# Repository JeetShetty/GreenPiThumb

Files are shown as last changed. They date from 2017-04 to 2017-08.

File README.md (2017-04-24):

# GreenPiThumb




GreenPiThumb is a program that automatically waters a plant based on soil moisture levels, and records and displays the following:

* Ambient temperature
* Ambient humidity
* Ambient light
* Soil moisture level
* Photographs of the plant

## Installation

### Standard Installation

Run this on a Raspberry Pi device:

```bash
sudo apt-get update
sudo apt-get install build-essential python-dev python-picamera
git clone https://github.com/adafruit/Adafruit_Python_DHT.git
cd Adafruit_Python_DHT
python setup.py install

cd ..
git clone https://github.com/JeetShetty/GreenPiThumb.git
cd GreenPiThumb
sudo pip install -r requirements.txt
cp greenpithumb/wiring_config.ini.example greenpithumb/wiring_config.ini
```

#### Running GreenPiThumb

After running the above installation steps on your Pi, run GreenPiThumb with a command following the template below:

```bash
sudo python greenpithumb/greenpithumb.py \
  --poll_interval 15 \
  --photo_interval 240 \
  --sleep_window "23:15-07:00" \
  --sleep_window "14:30-15:45" \
  --image_path "images/" \
  --moisture_threshold 900
```

### Dev Installation

Run this on a system for development:

```bash
sudo apt-get update
sudo apt-get install build-essential python-dev
git clone https://github.com/adafruit/Adafruit_Python_DHT.git
cd Adafruit_Python_DHT
sudo python setup.py install --force-test

cd ..
git clone https://github.com/JeetShetty/GreenPiThumb.git
cd GreenPiThumb
sudo pip install -r requirements.txt
sudo pip install -r dev_requirements.txt
cp greenpithumb/wiring_config.ini.example greenpithumb/wiring_config.ini
```

### Ansible Installation

This repository contains the GreenPiThumb backend, but GreenPiThumb also offers a [web frontend](https://github.com/JeetShetty/GreenPiThumb_Frontend_static) so you can check status of GreenPiThumb in your browser.

The instructions below explain how to install all backend and frontend components of GreenPiThumb to a Raspberry Pi device.

#### Local Self-Provision

If you're not familiar with Ansible, the simplest way to deploy GreenPiThumb is to install Ansible on the Pi itself and then use Ansible to self-provision the machine.

From a shell on the Raspberry Pi device itself, enter the following:

```bash
sudo apt-get update

# Install Ansible and dependencies
sudo apt-get install -y \
  libffi-dev \
  libyaml-dev \
  libpython2.7-dev \
  libssl-dev \
  python-pip \
  python2.7-dev
sudo pip install ansible paramiko PyYAML Jinja2 httplib2 six

# Install the Ansible GreenPiThumb role
sudo ansible-galaxy install JeetShetty.ansible-role-greenpithumb

# Create a minimal Ansible playbook to install GreenPiThumb
echo "- hosts: localhost
  roles:
    - { role: JeetShetty.ansible-role-greenpithumb }" > install.yml

# Self-provision for GreenPiThumb
sudo ansible-playbook install.yml
```

After this process completes, GreenPiThumb's backend and frontend will be running as services on the Pi. If you navigate to the Pi in a web browser (e.g. http://raspberrypi/ for a Pi named `raspberrypi`), you will see a dashboard similar to [greenpithumb.mtlynch.io](http://greenpithumb.mtlynch.io).

#### Remote Deployment

You can also use Ansible to deploy GreenPiThumb to a Raspberry Pi device from another Linux machine on the same network. You'll need to [install Ansible](http://docs.ansible.com/ansible/intro_installation.html) on your deployment machine (the non-Pi system).

Run the following commands on a Linux machine that has network access to your Pi device (e.g. on same local network):

```bash
PI_USER=pi                 # Change to the user on your Pi
PI_HOSTNAME=raspberrypi    # Change to your Pi's hostname.

# Install the Ansible GreenPiThumb role
sudo ansible-galaxy install JeetShetty.ansible-role-greenpithumb

# Create a minimal Ansible playbook to install GreenPiThumb
echo "- hosts: all
  roles:
    - { role: JeetShetty.ansible-role-greenpithumb}" > install.yml

# Provision the Pi using the playbook.
ansible-playbook install.yml \
  --user "${PI_USER}" \
  --ask-pass \
  --ask-sudo-pass \
  --become \
  --become-method sudo \
  -i "${PI_HOSTNAME},"
```

Ansible will prompt you for a password. Enter the password for the `PI_USER` account.

After this process completes, GreenPiThumb's backend and frontend will be running as services on the Pi. If you navigate to the Pi in a web browser (e.g. http://raspberrypi/ for a Pi named `raspberrypi`), you will see a dashboard similar to [greenpithumb.mtlynch.io](http://greenpithumb.mtlynch.io).

## Hardware

GreenPiThumb is designed for compatibility with a [Raspberry Pi device](https://www.raspberrypi.org/products/) running the [Raspbian OS](https://www.raspberrypi.org/downloads/raspbian/).

An example wiring can be found below:

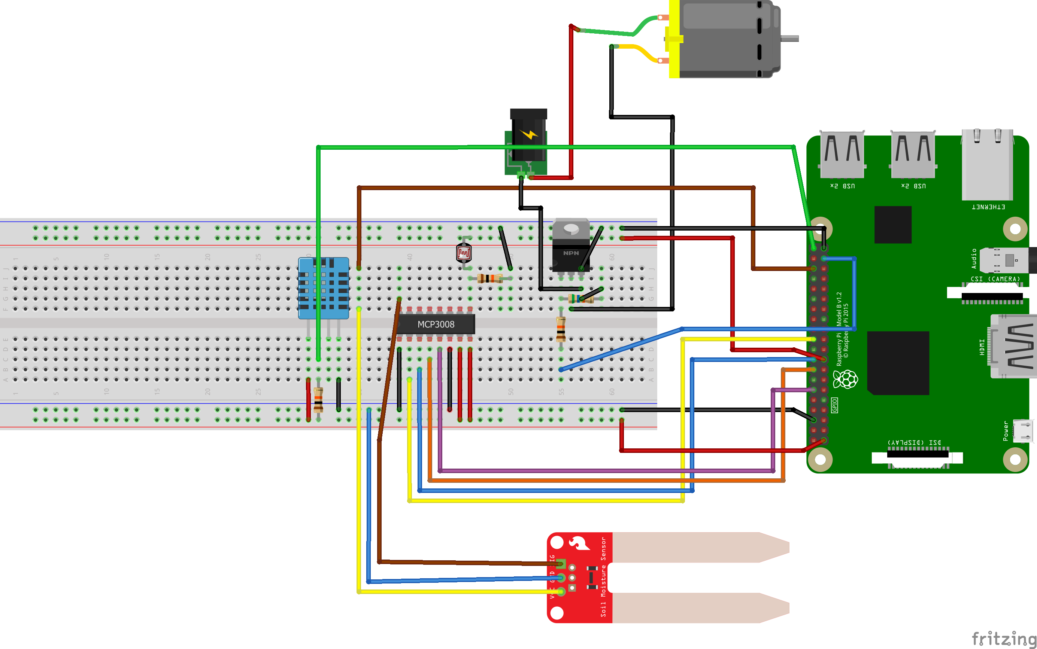
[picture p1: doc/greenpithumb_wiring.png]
Fritzing wiring diagram


The Fritzing diagram file for this diagram is available in the [`doc` folder](doc/).

## Related Repositories

* [GreenPiThumb_Frontend](https://github.com/JeetShetty/GreenPiThumb_Frontend): Web API to provide status about GreenPiThumb.
* [GreenPiThumb_Frontend_static](https://github.com/JeetShetty/GreenPiThumb_Frontend_static): An AngularJS web app for viewing GreenPiThumb status (the static portion of the web frontend).
* [ansible-role-greenpithumb](https://github.com/JeetShetty/ansible-role-greenpithumb): An [Ansible](https://www.ansible.com/how-ansible-works) role for deploying all parts of GreenPiThumb to a system.

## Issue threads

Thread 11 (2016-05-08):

DHT11 error code checking in humidity_sensor.py and temperature_sensor.py

JeetShetty, 2016-05-08:
Need to replace manually entered constants with constants from dht11 module

Closed 2016-06-28.

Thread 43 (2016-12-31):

Integrate GPIO stuff in moisture sensor

mtlynch, 2016-12-31:
I realized the code for `moisture_sensor.py` omits some critical elements we need. The moisture sensor is powered by the GPIO pins, because I think if we leave it powered all the time, the copper starts to corrode.

We can see how Dickson Chow does it here:

https://github.com/dicksondickson/PlantFriends/blob/7c172e9f80c2de2fdfc373d31a89de66787a7756/sensor_node/RFM69/sensor_node.ino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

So it looks like what we need to do is:

1. Set one pin to high, one pin to low
1. Read the sensor value from the ADC
1. Set both pins to low
1. Wait for capacitive effects to go away (he waits 88 milliseconds)
1. Repeat 1-2, but with the pins swapped and inverting the value from 1023
1. Turn off both pins
1. Average the two readings as the moisture level

JeetShetty, 2017-01-03:
What pins are we writing to in step 1? I'm confused about how this works through the ADC.

mtlynch, 2017-01-04:
So there 6 GPIO pins in play here. The ADC needs 4 pins, but the `moisture_sensor` module doesn't care about those 4 pins because it just needs an ADC instance (the instance worries about those pins and abstracts it away from `moisture_sensor`).

BUT `moisture_sensor` needs to control power to the sensor, so it needs to use two GPIO pins as output so that it can turn power on and off to the moisture sensor. Then it needs to know which ADC channel the moisture sensor is plugged into. In our schematic, the moisture sensor is plugged into ADC channel 7.

This is the quick 'n dirty script I used to test the soil moisture sensor as a standalone program. The numbers match the Fritzing schematic we have for the wiring.

```python
import time

import Adafruit_MCP3008
import RPi.GPIO as GPIO

# mtlynch: The moisture_sensor module wouldn't need to care about this stuff because it'd
# have an ADC initialized already
CLK  = 18
MISO = 23
MOSI = 24
CS   = 25
mcp = Adafruit_MCP3008.MCP3008(clk=CLK, cs=CS, miso=MISO, mosi=MOSI)

# Below this line is going to be kind of similar to what we want to do in moisture_sensor
ADC_CHANNEL_MOISTURE_SENSOR = 7

GPIO_PIN_1 = 16
GPIO_PIN_2 = 12

GPIO.setmode(GPIO.BCM)
GPIO.setup(GPIO_PIN_1, GPIO.OUT)
GPIO.setup(GPIO_PIN_2, GPIO.OUT)

i = 0
print('Reading MCP3008 values, press Ctrl-C to quit...')
# mtlynch: This just reads in a loop and alternates which pin has power on each iteration.
# In moisture_sensor, we'd want to read once with (pin_1 high, pin_2 low) and once with
# (pin_1 low, pin_2 high) and take the average.
while True:
    if i % 2 == 0:
        GPIO.output(GPIO_PIN_1, GPIO.LOW)
        GPIO.output(GPIO_PIN_2, GPIO.HIGH)
    else:
        GPIO.output(GPIO_PIN_1, GPIO.HIGH)
        GPIO.output(GPIO_PIN_2, GPIO.LOW)
    reading = mcp.read_adc(ADC_CHANNEL_MOISTURE_SENSOR)
    if i % 2 == 1:
        reading = 1023 - reading
    print reading
    time.sleep(0.5)
    i += 1
```

Closed 2017-01-20.

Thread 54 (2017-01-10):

Add GPIO.setmode

JeetShetty, 2017-01-10:
Seems to me that we want to use GPIO.BOARD, but you used GPIO.BCM in some of your code. I'm not clear on what each does, though.

mtlynch, 2017-01-12:
`GPIO.BCM` matches the numbers printed on the [Raspberry Pi cobbler](http://a.co/234GrbU) we use and in Fritzing.

I think the upside of `GPIO.BOARD` is that it will work across Raspberry Pi versions, but I'd rather sacrifice that to eliminate the confusion of having to keep looking at [this diagram](http://www.raspberrypi-spy.co.uk/wp-content/uploads/2012/06/Raspberry-Pi-GPIO-Layout-Model-B-Plus-rotated-2700x900-1024x341.png) to map the board numbers to the board-independent numbers.

Closed 2017-01-21.

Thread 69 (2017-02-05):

Connect pollers to actual database

mtlynch, 2017-02-05:
We have pollers that know how to write data to the database, but they're not hooked up to anything yet, so we need to add logic to the main script (greenpithumb.py) to connect each sensor to its appropriate poller and the pollers to the real sqlite database.

mtlynch, 2017-03-23:
Fixed in #89

Closed 2017-03-23.

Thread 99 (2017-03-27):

Can't kill GreenPiThumb with Ctrl+C

mtlynch, 2017-03-27:
Because of something weird we're doing with threading, GreenPiThumb doesn't exit when the user performs a `KeyboardInterrupt` (hits Ctrl+C). It eventually quits on the next poll, but the user can't quit immediately.

I think it's because the main thread is stuck blocking on reading from the record processing queue and can't be interrupted until something comes through.

Closed 2017-03-31.

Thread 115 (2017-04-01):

Camera Manager should name files based on UTC time zone

mtlynch, 2017-04-01:
We're going to run into issues parsing the files back otherwise (like #101) and it'll be good for all of our persistent storage to be in UTC time zone.

mtlynch, 2017-04-01:
Also we can probably drop the millisecond level precision here too.

Closed 2017-04-05.

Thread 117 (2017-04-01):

Camera poller needs to close camera manager

mtlynch, 2017-04-01:
Camera Manager needs to be closed when it is no longer needed, but the poller is not closing it.

Closed 2017-04-08.

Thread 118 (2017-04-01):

Camera manager should not take pictures at night

mtlynch, 2017-04-01:
We should integrate with the light sensor to detect when it's too dark to take a photo

JeetShetty, 2017-04-14:
Can I just add the light sensor to the ```_CameraPollWorker``` class? Are there any issues with the light sensor being read too frequently?

mtlynch, 2017-04-15:
Yeah that should work. I don't think there's much of a cost to reading the light sensor a lot.

Closed 2017-04-19.

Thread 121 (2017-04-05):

Drop seconds-level granularity

mtlynch, 2017-04-05:
Seconds-level granularity doesn't really make sense for anything in GreenPiThumb. The user doesn't need to schedule sensor polling intervals at the level of seconds and it doesn't make sense to take a picture of a plant at a frequency > 1x per min.

We should:
* Change command-line flags to take minutes rather than seconds
* Change the database to drop the seconds from the serialized timestamps

Closed 2017-04-07.

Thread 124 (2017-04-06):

Need to lower pump_manager's threshold for pumping

mtlynch, 2017-04-06:
The moisture I'm getting for dry soil is 860. We expected it to not water until it got below 300, so we need to increase the threshold a bit.

mtlynch, 2017-04-07:
Fixed in #126.

Closed 2017-04-07.

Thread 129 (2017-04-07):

Moisture threshold assumes constant temperature

mtlynch, 2017-04-07:
The temperature of the soil affects how conductive it is, but the soil moisture threshold does not take into account temperature (assumes soil's conductivity is fixed regardless of temperature).

We may want to use a more sophisticated threshold that takes temperature into consideration if temperature changes effect GreenPiThumb's soil moisture readings significantly.

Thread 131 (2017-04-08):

Pre-commit hook doesn't block on YAPF diff

mtlynch, 2017-04-08:
The pre-commit hook should block the commit if the YAPF diff turns up a delta, but currently it seems to just print a message and keep going. We should change the `build` so that it returns a failing exit code on a non-zero diff.

mtlynch, 2017-04-09:
Apparently this is a behavior change in YAPF:

https://github.com/google/yapf/issues/325

They're considering a fix, but there's a workaround possible:

https://github.com/google/yapf/issues/325#issuecomment-261552890

Closed 2017-04-13.

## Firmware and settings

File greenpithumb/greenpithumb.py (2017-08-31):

import argparse
import contextlib
import datetime
import logging
import Queue
import time

import Adafruit_DHT
import Adafruit_MCP3008
import picamera
import RPi.GPIO as GPIO

import adc_thread_safe
import camera_manager
import clock
import db_store
import dht11
import humidity_sensor
import light_sensor
import pi_io
import poller
import pump
import pump_history
import record_processor
import sleep_windows
import soil_moisture_sensor
import temperature_sensor
import wiring_config_parser

logger = logging.getLogger(__name__)


def configure_logging(verbose):
    """Configure the root logger for log output."""
    root_logger = logging.getLogger()
    handler = logging.StreamHandler()
    formatter = logging.Formatter(
        '%(asctime)s %(name)-15s %(levelname)-4s %(message)s',
        '%Y-%m-%d %H:%M:%S')
    handler.setFormatter(formatter)
    root_logger.addHandler(handler)
    if verbose:
        root_logger.setLevel(logging.INFO)
    else:
        root_logger.setLevel(logging.WARNING)


def read_wiring_config(config_filename):
    """Parses wiring config from a file."""
    logger.info('reading wiring config at "%s"', config_filename)
    with open(config_filename) as config_file:
        return wiring_config_parser.parse(config_file.read())


def make_adc(wiring_config):
    """Creates ADC instance based on the given wiring_config.

    Args:
        wiring_config: Wiring configuration for the GreenPiThumb.

    Returns:
        An ADC instance for the specified wiring config.
    """
    # The MCP3008 spec and Adafruit library use different naming for the
    # Raspberry Pi GPIO pins, so we translate as follows:
    # * CLK -> CLK
    # * CS/SHDN -> CS
    # * DOUT -> MISO
    # * DIN -> MOSI
    return adc_thread_safe.Adc(
        Adafruit_MCP3008.MCP3008(
            clk=wiring_config.gpio_pins.mcp3008_clk,
            cs=wiring_config.gpio_pins.mcp3008_cs_shdn,
            miso=wiring_config.gpio_pins.mcp3008_dout,
            mosi=wiring_config.gpio_pins.mcp3008_din))


def make_dht11_sensors(wiring_config):
    """Creates sensors derived from the DHT11 sensor.

    Args:
        wiring_config: Wiring configuration for the GreenPiThumb.

    Returns:
        A two-tuple where the first element is a temperature sensor and the
        second element is a humidity sensor.
    """
    local_dht11 = dht11.CachingDHT11(
        lambda: Adafruit_DHT.read_retry(Adafruit_DHT.DHT11, wiring_config.gpio_pins.dht11),
        clock.Clock())
    return temperature_sensor.TemperatureSensor(
        local_dht11), humidity_sensor.HumiditySensor(local_dht11),


def make_soil_moisture_sensor(adc, raspberry_pi_io, wiring_config):
    return soil_moisture_sensor.SoilMoistureSensor(
        adc, raspberry_pi_io, wiring_config.adc_channels.soil_moisture_sensor,
        wiring_config.gpio_pins.soil_moisture)


def make_light_sensor(adc, wiring_config):
    return light_sensor.LightSensor(adc,
                                    wiring_config.adc_channels.light_sensor)


def make_camera_manager(rotation, image_path, light_sensor):
    """Creates a camera manager instance.

    Args:
        rotation: The amount (in whole degrees) to rotate the camera image.
        image_path: The directory in which to save images.
        light_sensor: A light sensor instance.

    Returns:
        A CameraManager instance with the given settings.
    """
    camera = picamera.PiCamera(resolution=picamera.PiCamera.MAX_RESOLUTION)
    camera.rotation = rotation
    return camera_manager.CameraManager(image_path,
                                        clock.Clock(), camera, light_sensor)


def make_pump_manager(moisture_threshold, sleep_windows, raspberry_pi_io,
                      wiring_config, pump_amount, db_connection, pump_interval):
    """Creates a pump manager instance.

    Args:
        moisture_threshold: The minimum moisture level below which the pump
            turns on.
        sleep_windows: Sleep windows during which pump will not turn on.
        raspberry_pi_io: pi_io instance for the GreenPiThumb.
        wiring_config: Wiring configuration for the GreenPiThumb.
        pump_amount: Amount (in mL) to pump on each run of the pump.
        db_connection: Database connection to use to retrieve pump history.
        pump_interval: Maximum amount of time between pump runs.

    Returns:
        A PumpManager instance with the given settings.
    """
    water_pump = pump.Pump(raspberry_pi_io,
                           clock.Clock(), wiring_config.gpio_pins.pump)
    pump_scheduler = pump.PumpScheduler(clock.LocalClock(), sleep_windows)
    pump_timer = clock.Timer(clock.Clock(), pump_interval)
    last_pump_time = pump_history.last_pump_time(
        db_store.WateringEventStore(db_connection))
    if last_pump_time:
        logger.info('last watering was at %s', last_pump_time)
        time_remaining = max(
            datetime.timedelta(seconds=0),
            (last_pump_time + pump_interval) - clock.Clock().now())
    else:
        logger.info('no previous watering found')
        time_remaining = datetime.timedelta(seconds=0)
    logger.info('time until until next watering: %s', time_remaining)
    pump_timer.set_remaining(time_remaining)
    return pump.PumpManager(water_pump, pump_scheduler, moisture_threshold,
                            pump_amount, pump_timer)


def make_sensor_pollers(poll_interval, photo_interval, record_queue,
                        temperature_sensor, humidity_sensor,
                        soil_moisture_sensor, light_sensor, camera_manager,
                        pump_manager):
    """Creates a poller for each GreenPiThumb sensor.

    Args:
        poll_interval: The frequency at which to poll non-camera sensors.
        photo_interval: The frequency at which to capture photos.
        record_queue: Queue on which to put sensor reading records.
        temperature_sensor: Sensor for measuring temperature.
        humidity_sensor: Sensor for measuring humidity.
        soil_moisture_sensor: Sensor for measuring soil moisture.
        light_sensor: Sensor for measuring light levels.
        camera_manager: Interface for capturing photos.
        pump_manager: Interface for turning water pump on and off.

    Returns:
        A list of sensor pollers.
    """
    logger.info('creating sensor pollers (poll interval=%ds")',
                poll_interval.total_seconds())
    utc_clock = clock.Clock()

    make_scheduler_func = lambda: poller.Scheduler(utc_clock, poll_interval)
    photo_make_scheduler_func = lambda: poller.Scheduler(utc_clock, photo_interval)
    poller_factory = poller.SensorPollerFactory(make_scheduler_func,
                                                record_queue)
    camera_poller_factory = poller.SensorPollerFactory(
        photo_make_scheduler_func, record_queue=None)

    return [
        poller_factory.create_temperature_poller(temperature_sensor),
        poller_factory.create_humidity_poller(humidity_sensor),
        poller_factory.create_soil_watering_poller(
            soil_moisture_sensor,
            pump_manager),
        poller_factory.create_light_poller(light_sensor),
        camera_poller_factory.create_camera_poller(camera_manager)
    ]  # yapf: disable


def create_record_processor(db_connection, record_queue):
    """Creates a record processor for storing records in a database.

    Args:
        db_connection: Database connection to use to store records.
        record_queue: Record queue from which to process records.
    """
    return record_processor.RecordProcessor(
        record_queue,
        db_store.SoilMoistureStore(db_connection),
        db_store.LightStore(db_connection),
        db_store.HumidityStore(db_connection),
        db_store.TemperatureStore(db_connection),
        db_store.WateringEventStore(db_connection))


def main(args):
    configure_logging(args.verbose)
    logger.info('starting greenpithumb')
    wiring_config = read_wiring_config(args.config_file)
    record_queue = Queue.Queue()
    raspberry_pi_io = pi_io.IO(GPIO)
    adc = make_adc(wiring_config)
    local_soil_moisture_sensor = make_soil_moisture_sensor(
        adc, raspberry_pi_io, wiring_config)
    local_temperature_sensor, local_humidity_sensor = make_dht11_sensors(
        wiring_config)
    local_light_sensor = make_light_sensor(adc, wiring_config)
    camera_manager = make_camera_manager(args.camera_rotation, args.image_path,
                                         local_light_sensor)

    with contextlib.closing(
            db_store.open_or_create_db(args.db_file)) as db_connection:
        record_processor = create_record_processor(db_connection, record_queue)
        pump_manager = make_pump_manager(
            args.moisture_threshold,
            sleep_windows.parse(args.sleep_window),
            raspberry_pi_io,
            wiring_config,
            args.pump_amount,
            db_connection,
            datetime.timedelta(hours=args.pump_interval))
        pollers = make_sensor_pollers(
            datetime.timedelta(minutes=args.poll_interval),
            datetime.timedelta(minutes=args.photo_interval),
            record_queue,
            local_temperature_sensor,
            local_humidity_sensor,
            local_soil_moisture_sensor,
            local_light_sensor,
            camera_manager,
            pump_manager)
        try:
            for current_poller in pollers:
                current_poller.start_polling_async()
            while True:
                if not record_processor.try_process_next_record():
                    time.sleep(0.1)
        except KeyboardInterrupt:
            logger.info('Caught keyboard interrupt. Exiting.')
        finally:
            for current_poller in pollers:
                current_poller.close()
            raspberry_pi_io.close()


if __name__ == '__main__':
    parser = argparse.ArgumentParser(
        prog='GreenPiThumb',
        formatter_class=argparse.ArgumentDefaultsHelpFormatter)
    parser.add_argument(
        '-a',
        '--pump_amount',
        type=int,
        help='Volume of water (in mL) to pump each time the water pump is run',
        default=200)
    parser.add_argument(
        '-p',
        '--poll_interval',
        type=float,
        help='Number of minutes between each sensor poll',
        default=15)
    parser.add_argument(
        '-t',
        '--photo_interval',
        type=float,
        help='Number of minutes between each camera photo',
        default=(4 * 60))
    parser.add_argument(
        '-w',
        '--pump_interval',
        type=float,
        help='Max number of hours between plant waterings',
        default=(7 * 24))
    parser.add_argument(
        '-c',
        '--config_file',
        help='Wiring config file',
        default='greenpithumb/wiring_config.ini')
    parser.add_argument(
        '-s',
        '--sleep_window',
        action='append',
        type=str,
        default=[],
        help=('Time window during which GreenPiThumb will not activate its '
              'pump. Window should be in the form of a time range in 24-hour '
              'format, such as "03:15-03:45 (in the local time zone)"'))
    parser.add_argument(
        '-i',
        '--image_path',
        type=str,
        help='Path to folder where images will be stored',
        default='images/')
    parser.add_argument(
        '-d',
        '--db_file',
        help='Location to store GreenPiThumb database file',
        default='greenpithumb/greenpithumb.db')
    parser.add_argument(
        '-m',
        '--moisture_threshold',
        type=int,
        help=('Moisture threshold to start pump. The pump will turn on if the '
              'moisture level drops below this level'),
        default=0)
    parser.add_argument(
        '--camera_rotation',
        type=int,
        choices=(0, 90, 180, 270),
        help='Specifies the amount to rotate the camera\'s image.')
    parser.add_argument(
        '-v', '--verbose', action='store_true', help='Use verbose logging')
    main(parser.parse_args())

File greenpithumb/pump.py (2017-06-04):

import logging

logger = logging.getLogger(__name__)

# Pump rate in mL/s (4.3 L/min)
_PUMP_RATE_ML_PER_SEC = 4300.0 / 60.0

# Default amount of water to add to the plant (in mL) when pump manager detects
# low soil moisture.
DEFAULT_PUMP_AMOUNT = 200


class Pump(object):
    """Wrapper for a Seaflo 12V water pump."""

    def __init__(self, pi_io, clock, pump_pin):
        """Creates a new Pump wrapper.

        Args:
            pi_io: Raspberry Pi I/O interface.
            clock: A clock interface.
            pump_pin: Raspberry Pi pin to which the pump is connected.
        """
        self._pi_io = pi_io
        self._clock = clock
        self._pump_pin = pump_pin

    def pump_water(self, amount_ml):
        """Pumps the specified amount of water.

        Args:
            amount_ml: Amount of water to pump (in mL).

        Raises:
            ValueError: The amount of water to be pumped is invalid.
        """
        if amount_ml == 0.0:
            return
        elif amount_ml < 0.0:
            raise ValueError('Cannot pump a negative amount of water')
        else:
            logger.info('turning pump on (with GPIO pin %d)', self._pump_pin)
            self._pi_io.turn_pin_on(self._pump_pin)

            wait_time_seconds = amount_ml / _PUMP_RATE_ML_PER_SEC
            self._clock.wait(wait_time_seconds)

            logger.info('turning pump off (with GPIO pin %d)', self._pump_pin)
            self._pi_io.turn_pin_off(self._pump_pin)
            logger.info('pumped %.f mL of water', amount_ml)

        return


class PumpManager(object):
    """Pump Manager manages the water pump."""

    def __init__(self, pump, pump_scheduler, moisture_threshold, pump_amount,
                 timer):
        """Creates a PumpManager object, which manages a water pump.

        Args:
            pump: A pump instance, which supports water pumping.
            pump_scheduler: A pump scheduler instance that controls the time
                periods in which the pump can be run.
            moisture_threshold: Soil moisture threshold. If soil moisture is
                below this value, manager pumps water on pump_if_needed calls.
            pump_amount: Amount (in mL) to pump every time the water pump runs.
            timer: A timer that counts down until the next forced pump. When
                this timer expires, the pump manager runs the pump once,
                regardless of the moisture level.
        """
        self._pump = pump
        self._pump_scheduler = pump_scheduler
        self._moisture_threshold = moisture_threshold
        self._pump_amount = pump_amount
        self._timer = timer

    def pump_if_needed(self, moisture):
        """Run the water pump if there is a need to run it.

        Args:
            moisture: Soil moisture level

        Returns:
            The amount of water pumped, in mL.
        """
        if self._should_pump(moisture):
            self._pump.pump_water(self._pump_amount)
            self._timer.reset()
            return self._pump_amount

        return 0

    def _should_pump(self, moisture):
        """Returns True if the pump should be run."""
        if not self._pump_scheduler.is_running_pump_allowed():
            return False
        return (moisture < self._moisture_threshold) or self._timer.expired()


class PumpScheduler(object):
    """Controls when the pump is allowed to run."""

    def __init__(self, local_clock, sleep_windows):
        """Creates new PumpScheduler instance.

        Args:
            local_clock: A local clock interface
            sleep_windows: A list of 2-tuples, each representing a sleep window.
                Tuple items are datetime.time objects.
        """
        self._local_clock = local_clock
        self._sleep_windows = sleep_windows

    def is_running_pump_allowed(self):
        """Returns True if OK to run pump, otherwise False.

        Pump is not allowed to run from the start of a sleep window (inclusive)
        to the end of a sleep window (exclusive).
        """
        current_time = self._local_clock.now().time()

        for sleep_time, wake_time in self._sleep_windows:
            # Check if sleep window wraps midnight.
            if wake_time < sleep_time:
                if current_time >= sleep_time or current_time < wake_time:
                    return False
            else:
                if sleep_time <= current_time < wake_time:
                    return False

        return True

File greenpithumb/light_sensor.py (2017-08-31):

import logging

logger = logging.getLogger(__name__)

_LIGHT_SENSOR_MIN_VALUE = 0
_LIGHT_SENSOR_MAX_VALUE = 1023


class Error(Exception):
    pass


class LightSensorLowError(Error):
    pass


class LightSensor(object):
    """Wrapper for light sensor."""

    def __init__(self, adc, channel):
        """Creates a new LightSensor wrapper.

        Args:
            adc: ADC(analog to digital) interface to receive
                analog signals from light sensor.
            channel: ADC channel to which the light sensor is connected.
        """
        self._adc = adc
        self._channel = channel

    def light(self):
        """Returns light level as percentage.

        Raises:
            LightSensorLowError: Ambient light level is lower than the minimum
                expected value.
        """
        light = self._adc.read_adc(self._channel)
        logger.info('light reading = %d', light)

        if light < _LIGHT_SENSOR_MIN_VALUE:
            raise LightSensorLowError(
                ('Light sensor reading of %i is less than the minimum '
                 'expected value of %i.') % (light, _LIGHT_SENSOR_MIN_VALUE))

        light_as_pct = 100 * (float(light - _LIGHT_SENSOR_MIN_VALUE) / (
            _LIGHT_SENSOR_MAX_VALUE - _LIGHT_SENSOR_MIN_VALUE))

        return light_as_pct

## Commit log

2016-04-14 Adding a PumpManager class
    Adds a PumpManager class with unit tests. One unit test works, two fail, and
    one is not implemented yet.
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2016-04-16 Adding clock, unit tests for pump
    Adds an implementation for a clock interface.
    Adds unit tests and a stub for the pump_water method of Pump class.
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2016-05-10 Adding YAPF to build, fixing formatting (#12)
    Adding YAPF to the build to enforce formatting style.
    Fixing all source code to have style-compliant formatting.
    Changing all tabs to spaces.
    [clock.py, light_sensor.py, moisture_sensor.py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]
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2016-05-15 Adding a now() method to clock (#18)
    * Adding a now() method to clock
    Adds a now() method to the clock class that returns time in UTC.
    * Fixing travis file
    [clock.py, test_clock.py]
2016-05-20 Adding a basic command-line interface (#20)
    * Adding a basic command-line interface
    Adds a basic command line interface for GreenPiThumb. At this point, all it
    does is read each sensor and print out the value.
    Since we're not running on real hardware yet, adds a fake_sensors module that
    generates random sensor values.
2016-05-27 Adding docstring checker and pylint checks (#22)
    Adding two additional automated checks
    * pyflakes will look for cruft like variables we declare but don't ever use or
    imports we make but don't use (it flagged one in pump.py)
    * docstringchecker is a pylint plugin that will check to make sure all of
    our docstrings are properly formatted (it flagged two instances where we had
    trailing whitespace).
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2016-08-16 Adjust code to account for ADC returning ints instead of floats. Fix CREATE TABLE statements. (#29)
    [db_store.py, light_sensor.py, test_db_store.py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]
2016-08-16 Mtlynch force line endings (#31)
    * Configure git to automatically use LF for line endings
    Adds a .gitattributes file to tell git to automatically convert \r\n line
    endings to just \n.
    Fixes existing files that are using \r\n instead of \n.
    * Replacing tabs with spaces
    [db_store.py, test_db_store.py]
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2017-01-02 Implement IO class. (#38)
    * Remove adc.py, add io.py, update modules as necessary.
2017-01-04 Adding wiring config parser (#42)
    Adding a parser for GreenPiThumb's wiring configuration (which includes the
    wiring information for the GPIO pins and ADC channels).
    Also adds a sample wiring configuration and updates the README with
    instructions for how to use the sample.
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2017-01-09 Adding support in wiring config for soil moisture (#47)
    The soil moisture sensor needs to use two GPIO pins for power, so this adds
    support for specifying those pins in the wiring config.
2017-01-10 Fix accidental removal of moisture sensor pins. (#52)
    [wiring_config_parser.py]
2017-01-20 Fixing minimum light sensor value (#58)
    In practice, it seems like the light sensor can actually go down to near 0
    when it's completely covered up, so reducing the min to 0.
    [light_sensor.py, test_light_sensor.py]
2017-01-27 Connecting actual components to the code (#62)
    Getting rid of the fake_sensors module and connecting the real components
    in the main greenpithumb.py file.
    Also fixes the example wiring config to match the GreenPiThumb reference
    schematic.
    [greenpithumb.py]
2017-01-30 Fixing TODO about wiring naming (#64)
    I thought I had the naming wrong for the MCP3008's pins, but it turns out
    that the MCP3008 spec and the Adafruit library just use different names for
    the same pins. This replaces the TODO with an explanation of the
    translation.
    [greenpithumb.py]
2017-01-30 Fix soil sensor (#63)
    * Updating driver to match soil moisture sensor's constructor
    We've updated the soile moisture sensor's constructor to require additonal
    parameters so this PR updates the driver file to match the new parameters.
    * Wrapping GPIO in pi_io
    * Fixing mode
    * Fixing pin numbering in wiring config
    [greenpithumb.py, pi_io.py]
2017-03-09 Deleting functionality related to reservoir (#73)
    * Deleting functionality related to reservoir
    This functionality was cut for v1, so removing the related code.
    Fixes #72.
    * Removing weight sensor
    [db_store.py, poller.py, test_db_store.py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]
2017-03-09 Fixing quote characters in DB store tests (#75)
    Changing to single quotes for consistency with rest of the project.
    [test_db_store.py]
2017-03-12 Hooking up actual database (#77)
    Hooking up greenpithumb's main script to an actual database.
    Adding a function to automatically create the GreenPiThumb database or open an
    existing database file.
    Fixes #65
    [db_store.py, greenpithumb.py, test_db_store.py]
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2017-03-16 Changing poller semantics to make them stoppable (#81)
    The pollers originally were designed without a way of stopping the background
    polling thread. In practice, we probably don't really need a way of closing
    the thread, but in unit tests, we need a way of killing the background thread
    when the test ends, otherwise the tests spawn a bunch of threads that never
    stop running.
    I'm not sure why the existing tests never triggered this problem, but when we
    change the pollers to be record queue based, I'm seeing this issue, so fixing
    the tests ahead of that change.
    [poller.py, test_poller.py]
2017-03-23 Changing the pollers to record updates through records (#82)
    Changing the poller classes so that instead of writing directly to the DbStore
    classes, they write DB records to a records queue.
    This works around problems of DB stores that were initialized in one thread
    getting called by the distinct threads created by the pollers.
    [poller.py, test_poller.py]
2017-03-23 Fixing flag name for db_file (#84)
    [greenpithumb.py]
2017-03-23 Adding commit calls to DbStore (#85)
    After we execute a statement to insert something into a SQLite table, we need
    to call commit on the DB connection to write the change.
    This adds the necessary commits and also changes DbStore so that it keeps a
    reference to the connection instead of just the cursor.
2017-03-23 Fixing the default value of the wiring config path (#86)
    Changing the wiring config path so that it agrees with what's specified in the
    README and shares a folder with greenpithumb.db
    [greenpithumb.py]
2017-03-23 Adding diagnostic logging (#87)
    * Adding diagnostic logging
    Adding logging to all of the sensors and some of the other components to make
    it easier to see what's going on while GreenPiThumb runs.
    * Tweaking logging format and adding logging to DHT11
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2017-03-25 Refactoring method names in DbStore classes (#90)
    The calling semantics of the DbStore classes are a bit redundant because we
    end up with calls like 'temperature_store.store_temperature'. The class name
    gives the type, so we don't have to repeat it in the method. I think if we do
    this, it opens up the door to some refactoring around managing multiple
    db store instances of different types.
2017-03-26 Merging SoilMoisturePoller and WateringEventPoller (#95)
    It turns out things are a lot simpler when we combine the poller for checking
    soil moisture with the poller responsible for running the pump based on soil
    moisture. Now, the SoilWateringPoller can check soil moisture, store the
    record in the DB, but then use the same reading to determine if it needs to
    pump water.
    Because of this, we can get rid of the get_latest method on SoilMoistureStore,
    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
2017-03-27 Refactoring pollers (#96)
    The goal of the refactoring is to fix two problems:
    1. SensorPollBase has a design flaw in that it runs in the main thread, but
    holds instance data that is meant to be operated on in the background thread.
    This is error-prone because if SensorPollBase touches its members that are
    not thread safe while the background thread is also touching it, we can get
    concurrency bugs. We should redesign it so that it doesn't have access to
    any instance data it shouldn't be touching.
    2. There are two ways of instantiating the pollers: through the
    SensorPollerFactory and by instantiating the objects directly. Offering an
    API with multiple ways of doing the same thi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
    [poller.py, test_poller.py]
2017-03-28 Fix PumpScheduler to handle updated sleep window format. (#92)
2017-03-30 Changing timestamp serialization for database (#101)
    dateutil's parsing is apparently very slow because it has to do a lot of
    regexing on the date string to figure out its format automatically. We don't
    strictly need this because we can just serialize it to a format that's
    easier to parse back.
    This changes the date serialization so that dates are always stored as UTC
    times (so that we don't have to try to serialize/deserialize time zone). This
    also removes milliseconds precision from the serialized format because it
    wasn't a deliberate choice to add it and the timestamps probably aren't
    precise to the millisecond of when the sensor was read.
    This should fix #98.
    [db_store.py, test_db_store.py]
2017-03-30 Changing polling to occur on time boundaries (#100)
    * Changing polling to occur on time boundaries
    In the current implementation, each sensor starts reading immediately, then
    polls every n seconds. This means that the readings depend on when the
    greenpithumb started, so if a user runs greenpithumb on two different days
    with two different start times, the reading timestamps won't be aligned.
    By changing the polling time to happen on interval boundaries, we get aligned
    readings no matter when we start the greenpithumb process.
    As a side effect, this doesn't solve the uninterruptible process issue (#99)
    but it should make it easier to fix since we're getting rid of most of the
    th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
    [poller.py, test_poller.py]
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2017-03-31 Adding a thread-safe wrapper around the ADC (#103)
    Multiple threads share access to the ADC instance, so we need a way to make
    it thread-safe.
2017-03-31 Changes main script so user can Ctrl+C to exit (#104)
    * Changes main script so user can Ctrl+C to exit
    Changes the main script and record processor so that we're not blocking
    indefinitely until a polling event occurs.
    This fixes #99
    * Lowering sleep time between record processings
    [greenpithumb.py, record_processor.py, test_record_processor.py]
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2017-04-03 Increasing the default time between sensor polls (#113)
    Bumping up from once every 500ms to once every 15m
2017-04-03 Changing pollers to use UTC time (#109)
    * Changing pollers to use UTC time
    * Fixing formatting
    [greenpithumb.py, poller.py, test_poller.py]
2017-04-03 Adding poller and log messages for camera (#116)
    Adding a separate photo interval flag to control frequency of photos
    Adding logging message in camera_manager
2017-04-05 Changing camera to save hi res files and use UTC time (#119)
    * Changing camera to save hi res files and use UTC time
    Changing camera poller to use UTC time and a string timestamp format to match
    the database timestamp format.
    Changing the camera's resolution to be the max resolution.
    * Changing photo filename to use minutes level precision
2017-04-05 Adding a default value for sleep_window flag (#120)
    Otherwise it gets set to None and the sleep window parser crashes.
    [greenpithumb.py]
2017-04-07 Changing moisture threshold to flag (#126)
    It looks like moisture levels may vary from system to system, so instead of
    hardcoding the moisture threshold at which the pump starts running, we make
    it a command-line flag so that it is easily configurable.
2017-04-07 Fixing measurement bug in soil moisture sensor (#125)
    The second reading was coming in wrong because we weren't turning off both
    GPIO pins before we slept, so there was probably some remnant charge on the
    first pin during the second read. Adding in a turn_pin_off call to ensure
    that both pins are off and have time for the charge to dissipate.
    [moisture_sensor.py, test_moisture_sensor.py]
2017-04-08 Update camera poller to close the camera when polling is complete. (#127)
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2017-04-09 Changing poll_interval to be a timedelta (#132)
    This fixes a bug in poller where it was treating the interval as seconds in
    one spot and minutes in another.
    This is really a temporary workaround until we refactor out the poll
    scheduling logic because I think this bug shows we're not testing it
    sufficiently and the way the code is currently organized, it's hard to test
    the poll scheduling part.
    [greenpithumb.py, poller.py, test_poller.py]
2017-04-11 Fix import ordering in greenpithumb.py. (#133)
    [greenpithumb.py]
2017-04-12 Refactoring poll scheduling into Scheduler class (#136)
    Poll scheduling is complex enough that it merits its own class with direct
    unit tests. Refactoring the scheduling logic into a Scheduler class and adding
    tests for scheduling.
    Fixes #134
    [greenpithumb.py, poller.py, test_poller.py]
2017-04-15 Fixing last_poll_time function (#137)
    * Fixing last_poll_time function
    last_poll_time was returning timestamps as ints, whereas the callers were
    expecting datetimes. Also, the way that last_poll_time was getting updated
    wasn't really intuitive, so updated the code so that last_poll_time only
    updates after the scheduler waits through a poll boundary.
    * Making a clearer distinction in Scheduler between UNIX time and datetime
    The Scheduler uses both UNIX timestamps and datetimes, but it's not always
    clear which variable/function is using which format. This can lead to bugs
    where types are used or compared incorrectly. Changing the naming so that UNIX
    timestamps are always named t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
    [poller.py, test_poller.py]
2017-04-17 Adding Fritzing diagram to repo (#140)
    * Adding Fritzing diagram to repo
    Adding an example GreenPiThumb wiring and image to repo and referencing it in
    the README.
    * Updating Fritzing diagram
    [greenpithumb.fzz]
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2017-04-22 Adding support for camera rotation as a command-line flag (#141)
    I just repositioned my camera and the only way to do it was upside down, so
    I realized this is probably a useful feature.
2017-05-19 Add missing @mock.patch decorators to camera manager tests. (#144)
    [test_camera_manager.py]
2017-06-01 Fixing pump_interval flag (#145)
    [greenpithumb.py]
2017-06-01 Switching from PlantFriends soil sensor to SparkFun (#146)
    * Switching from PlantFriends soil sensor to SparkFun
    Changes code to use the SparkFun soil moisture sensor instead of the
    PlantFriends soil moisture sensor. The SparkFun cannot reverse its polarity
    like the PlantFriends, so it is constantly connected to ground and only needs
    one GPIO pin to flip up and down for readings.
    Updates the code and the Fritzing diagram.
    * Changing soil moisture GPIO pin to GPIO16
    * Fixing pins -> pin
    [greenpithumb.fzz]
2017-06-04 Fixing Fritzing diagram (#147)
    MCP3008 label was upside-down.
    [greenpithumb.fzz]
2017-06-04 Making water pump volume configurable via command line (#148)
    Adding a command-line flag to let the user specify the volume of water to pump
    on each pump run.
2017-06-16 Refactoring greenpithumb.py (#149)
    * Refactoring greenpithumb.py
    This file had gotten a bit unwieldy with several functions taking a million
    args and doing unrelated actions. Refactors to try to break it into more
    logically cohesive chunks.
    * Fixing missing return in light sensor
    * Updating based on code review notes
    [greenpithumb.py]
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
